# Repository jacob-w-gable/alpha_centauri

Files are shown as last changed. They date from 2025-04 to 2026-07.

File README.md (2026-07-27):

# Alpha Centauri KBD

This is a custom keyboard with a custom keymap that is specifically tailored to my hands and workflow style. It takes heavy inspiration from [crkbd v3](https://github.com/foostan/crkbd). The primary difference is the vertical spacing of the keys, and I have also removed one key from the outside column. The PCB is designed to support either MX or Choc v2 switches without sacrificing LED support. The keymap has been designed for comfort and efficiency, prioritizing typing/programming over other activities such as gaming.

### Assembled Choc Keyboard

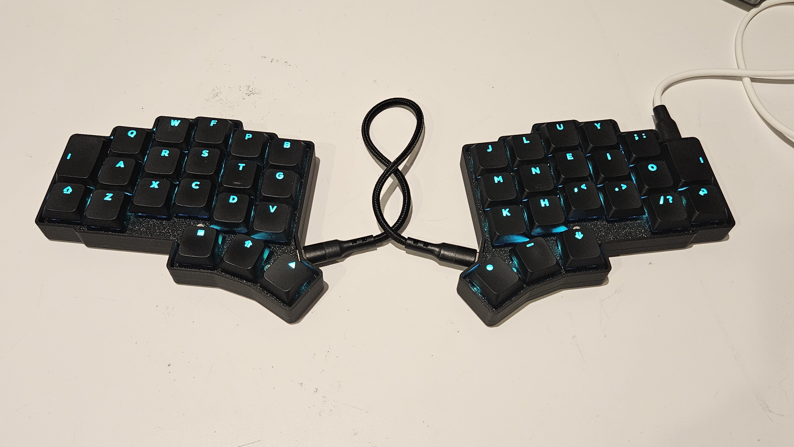
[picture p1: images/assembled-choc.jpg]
Choc variant


### Assembled MX Keyboard

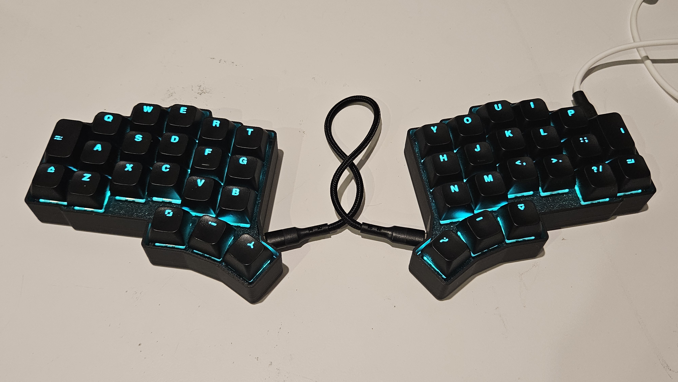
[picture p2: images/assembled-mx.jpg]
MX variant


## Detailed Documentation

- [Quickstart](https://github.com/jacob-w-gable/alpha_centauri/wiki/Quickstart)
- [Designing/Fabricating the PCB](https://github.com/jacob-w-gable/alpha_centauri/wiki/Designing-and-Fabricating-PCB)
- TODO: PCB Assembly
- [Building/Flashing the Firmware](https://github.com/jacob-w-gable/alpha_centauri/wiki/Building-and-Flashing-Firmware)
- TODO: Printing the Case
- TODO: Final Assembly
- [Technical Layer Reference](https://github.com/jacob-w-gable/alpha_centauri/wiki/Technical-Layer-Reference)
- [Design Philosophy](https://github.com/jacob-w-gable/alpha_centauri/wiki/Design)

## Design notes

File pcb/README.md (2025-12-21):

# PCB Files

These are the files required to edit the PCB in Kicad. One thing that makes this PCB stand out, is the fact that you can use hotswap sockets for either MX or Choc style switches, without compromising the ability to use per-key LEDs. While this does unfortunately cut off one of the pads, it does not make an electrical difference.

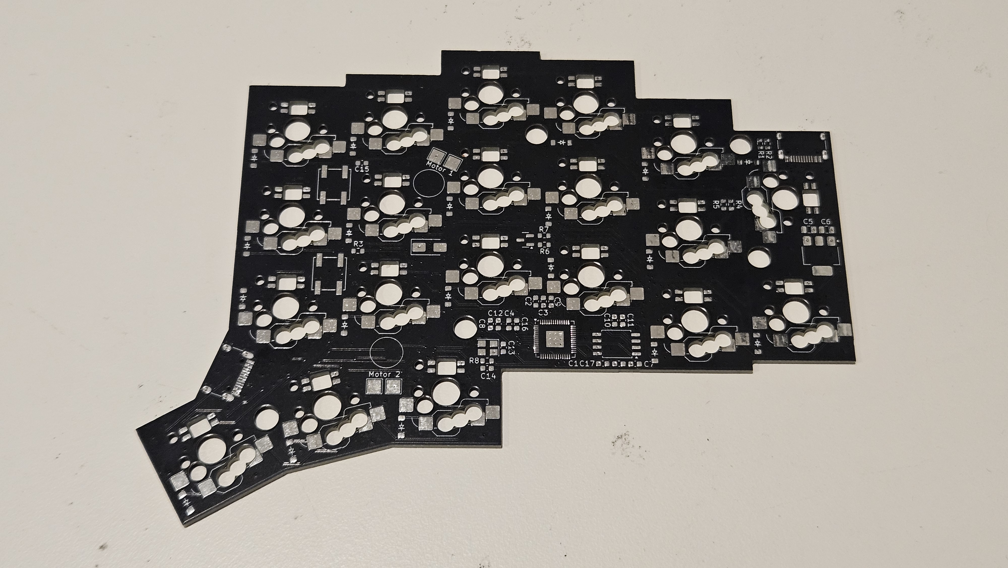
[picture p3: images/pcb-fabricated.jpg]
Fabricated

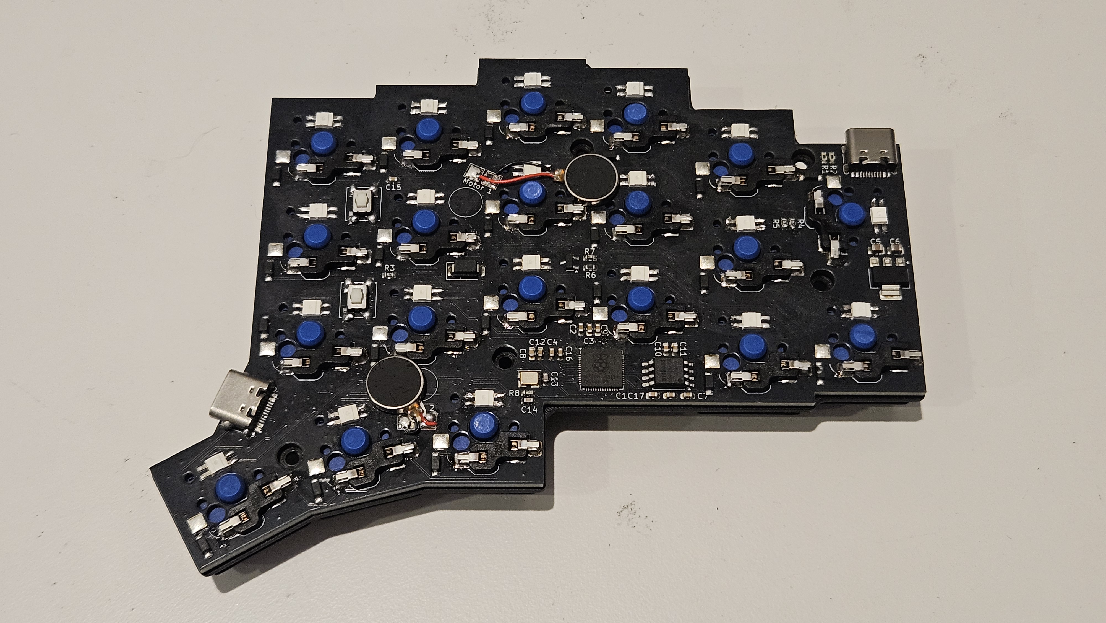
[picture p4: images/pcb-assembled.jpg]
Assembled


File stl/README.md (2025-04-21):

# STL files

These are the files for 3D-printing the keyboard case. These cases are compatible with Amoeba v1 or Amoeba King PCB's. Amoeba Royale's are not supported. The primary difference between the two versions is the structural supports in the middle of the keyboard, which Amoeba Royale's do not provide enough room for. The other difference is that the case for Amoeba King's is slightly larger, to compensate for the slightly larger PCB's. 

Of course, the advantage of Amoeba King's over Amoeba v1's, is support for per-key LED backlighting. 

If you simply want to handwire, either case will do, though the King case will use _slightly_ more material. 

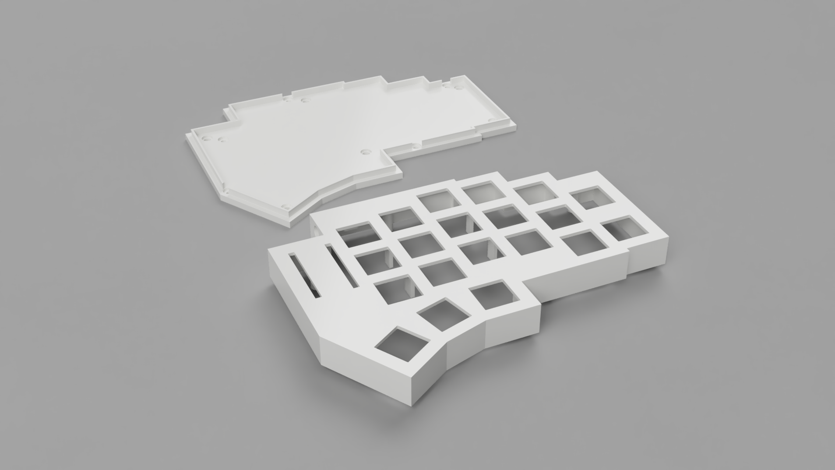
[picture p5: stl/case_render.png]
Case Render


## Printing

No special instructions, considering no supports are necessary. But for consistency, here are some parameters I used:

* Material: PLA
* Layer Height: 0.12mm
* Infill: 15%
* Nozzle Size: 0.4mm

## Firmware Differences

You may find a slight difference in the diode direction, depending on which PCB you are using. For me personally, my King's required

```
  "diode_direction": "ROW2COL",
```

while my v1's required

```
  "diode_direction": "COL2ROW",
```

The direction is ROW2COL by default, so take note of this difference if you want to use Amoeba v1's.

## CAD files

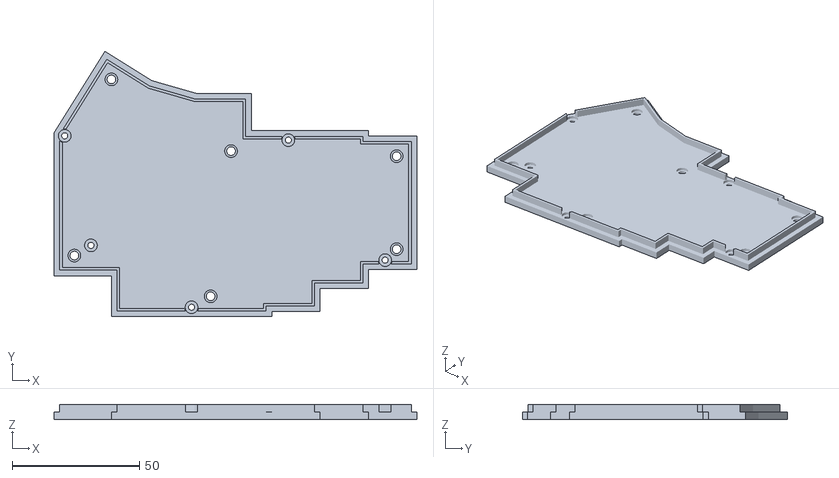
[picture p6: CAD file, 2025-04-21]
stl/amoeba_king/bottom-left.stl
142.5 x 104.2 x 6.00

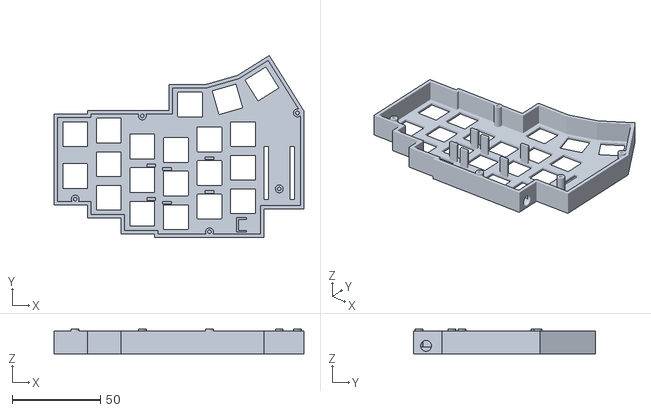
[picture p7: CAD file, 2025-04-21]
stl/amoeba_v1/top-left.stl
141.5 x 103.0 x 14.0

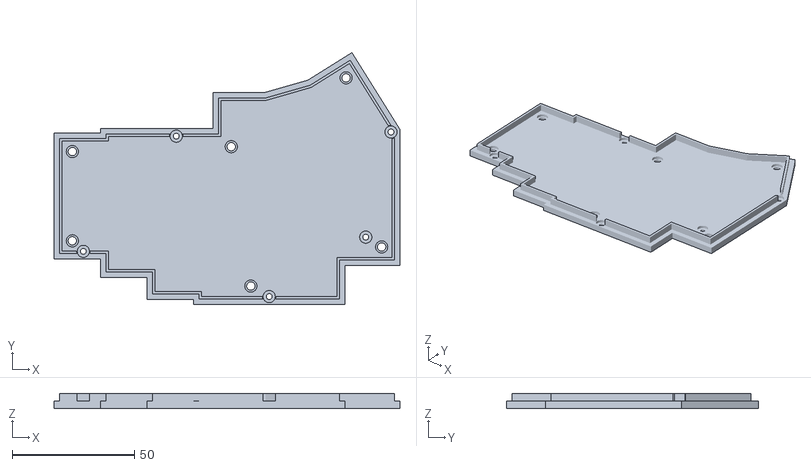
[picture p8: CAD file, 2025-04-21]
stl/amoeba_v1/bottom-right.stl
141.5 x 103.0 x 6.00

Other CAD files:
stl/amoeba_king/bottom-right.stl
stl/amoeba_v1/top-right.stl
stl/amoeba_king/top-left.stl
stl/amoeba_king/top-right.stl
stl/amoeba_v1/bottom-left.stl

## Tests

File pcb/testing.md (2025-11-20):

# Testing PCB

## Before powering on

1. Test GND and 3v3 = 0 ohm
1. Test GND and 5v = 0 ohm
1. Test 3v3 and 5v = 0 ohm
1. Test for continuity between GND and all GND pins on rp2040
1. Test for continuity between 3v3 and all 3v3 pins on rp2040
1. Test for shorts on both sides of all resistors and capacitors. Note: One of the resistors by the mosfet will beep - this is noraml. Also seems like it can happen on the data resistors if you push hard enough.
1. Test for no continuity between each column with each other column
1. Test for no continuity between each row with each other row
1. Test for no continuity between each column with each row
1. Test for continuity between each column with rp2040
1. Test for continuity between each row with rp2040
1. Test for continuity on GND of each capacitor
1. Test for continuity on 3v3 of each 3v3 capacitor
1. Test for continuity on 1v1 of each 1v1 capacitor (just compare them against each other)
1. Test for continuity to 1v1 pins of rp2040 against one the side of one of the 1v1 capacitors
1. Test for no continuity between 3v3 and 1v1 capacitor sides
1. Test for no continuity between the two inputs of the mosfet
1. Test for no continuity between each pin of the flash device
1. Test for continuity between the GND pin of the flash device and GND
1. Test for continuity between the VCC pin of the flash device and 3v3
1. Test for continuity between each pin with the rp2040
1. Test for no continuity between the buttons, unless pressed
1. Test for no continuity between each complimenting side of the data resistors
1. Test for continuity between USB and data resistors
1. Test for continuity between data resistors and rp2040
1. Test for continuity between GND and GND pads of crystal
1. Test for continuity between XIN and rp2040
1. Test for continuity between XOUT (side of a resistor) and rp2040
1. Test for continuity between the other side of that resistor and crystal
1. Test for continuity between the data pins of the slave USB and rp2040
1. Test for continuity between LED input to rp2040
1. Test for continuity between haptic control line to rp2040
1. Test for no continuity between LED input and 3v3
1. Test for no continuity between columns and 3v3
1. Test for no continuity between rows and 3v3
1. Test for no continuity between split kb data line and 3v3
1. Test for no continuity between haptic control line and 3v3
1. Test for no continuity between haptic control line and LED input
1. Test for no continuity between haptic control line and data lines
1. Test for no continuity between LED input and data lines

## After powering on

1. Measure 1v1, 3v3, and 5v voltage.

## Notes

- The top row is the most important. It contains the 1v1 and 3v3 reference points, D+/D-, and QSPI pins. If these pins have good connections while others have poor connections (within reason), then the flashing should at least work.
- Might want to wait to put the LEDs and sockets on until after we can verify that the flashing works

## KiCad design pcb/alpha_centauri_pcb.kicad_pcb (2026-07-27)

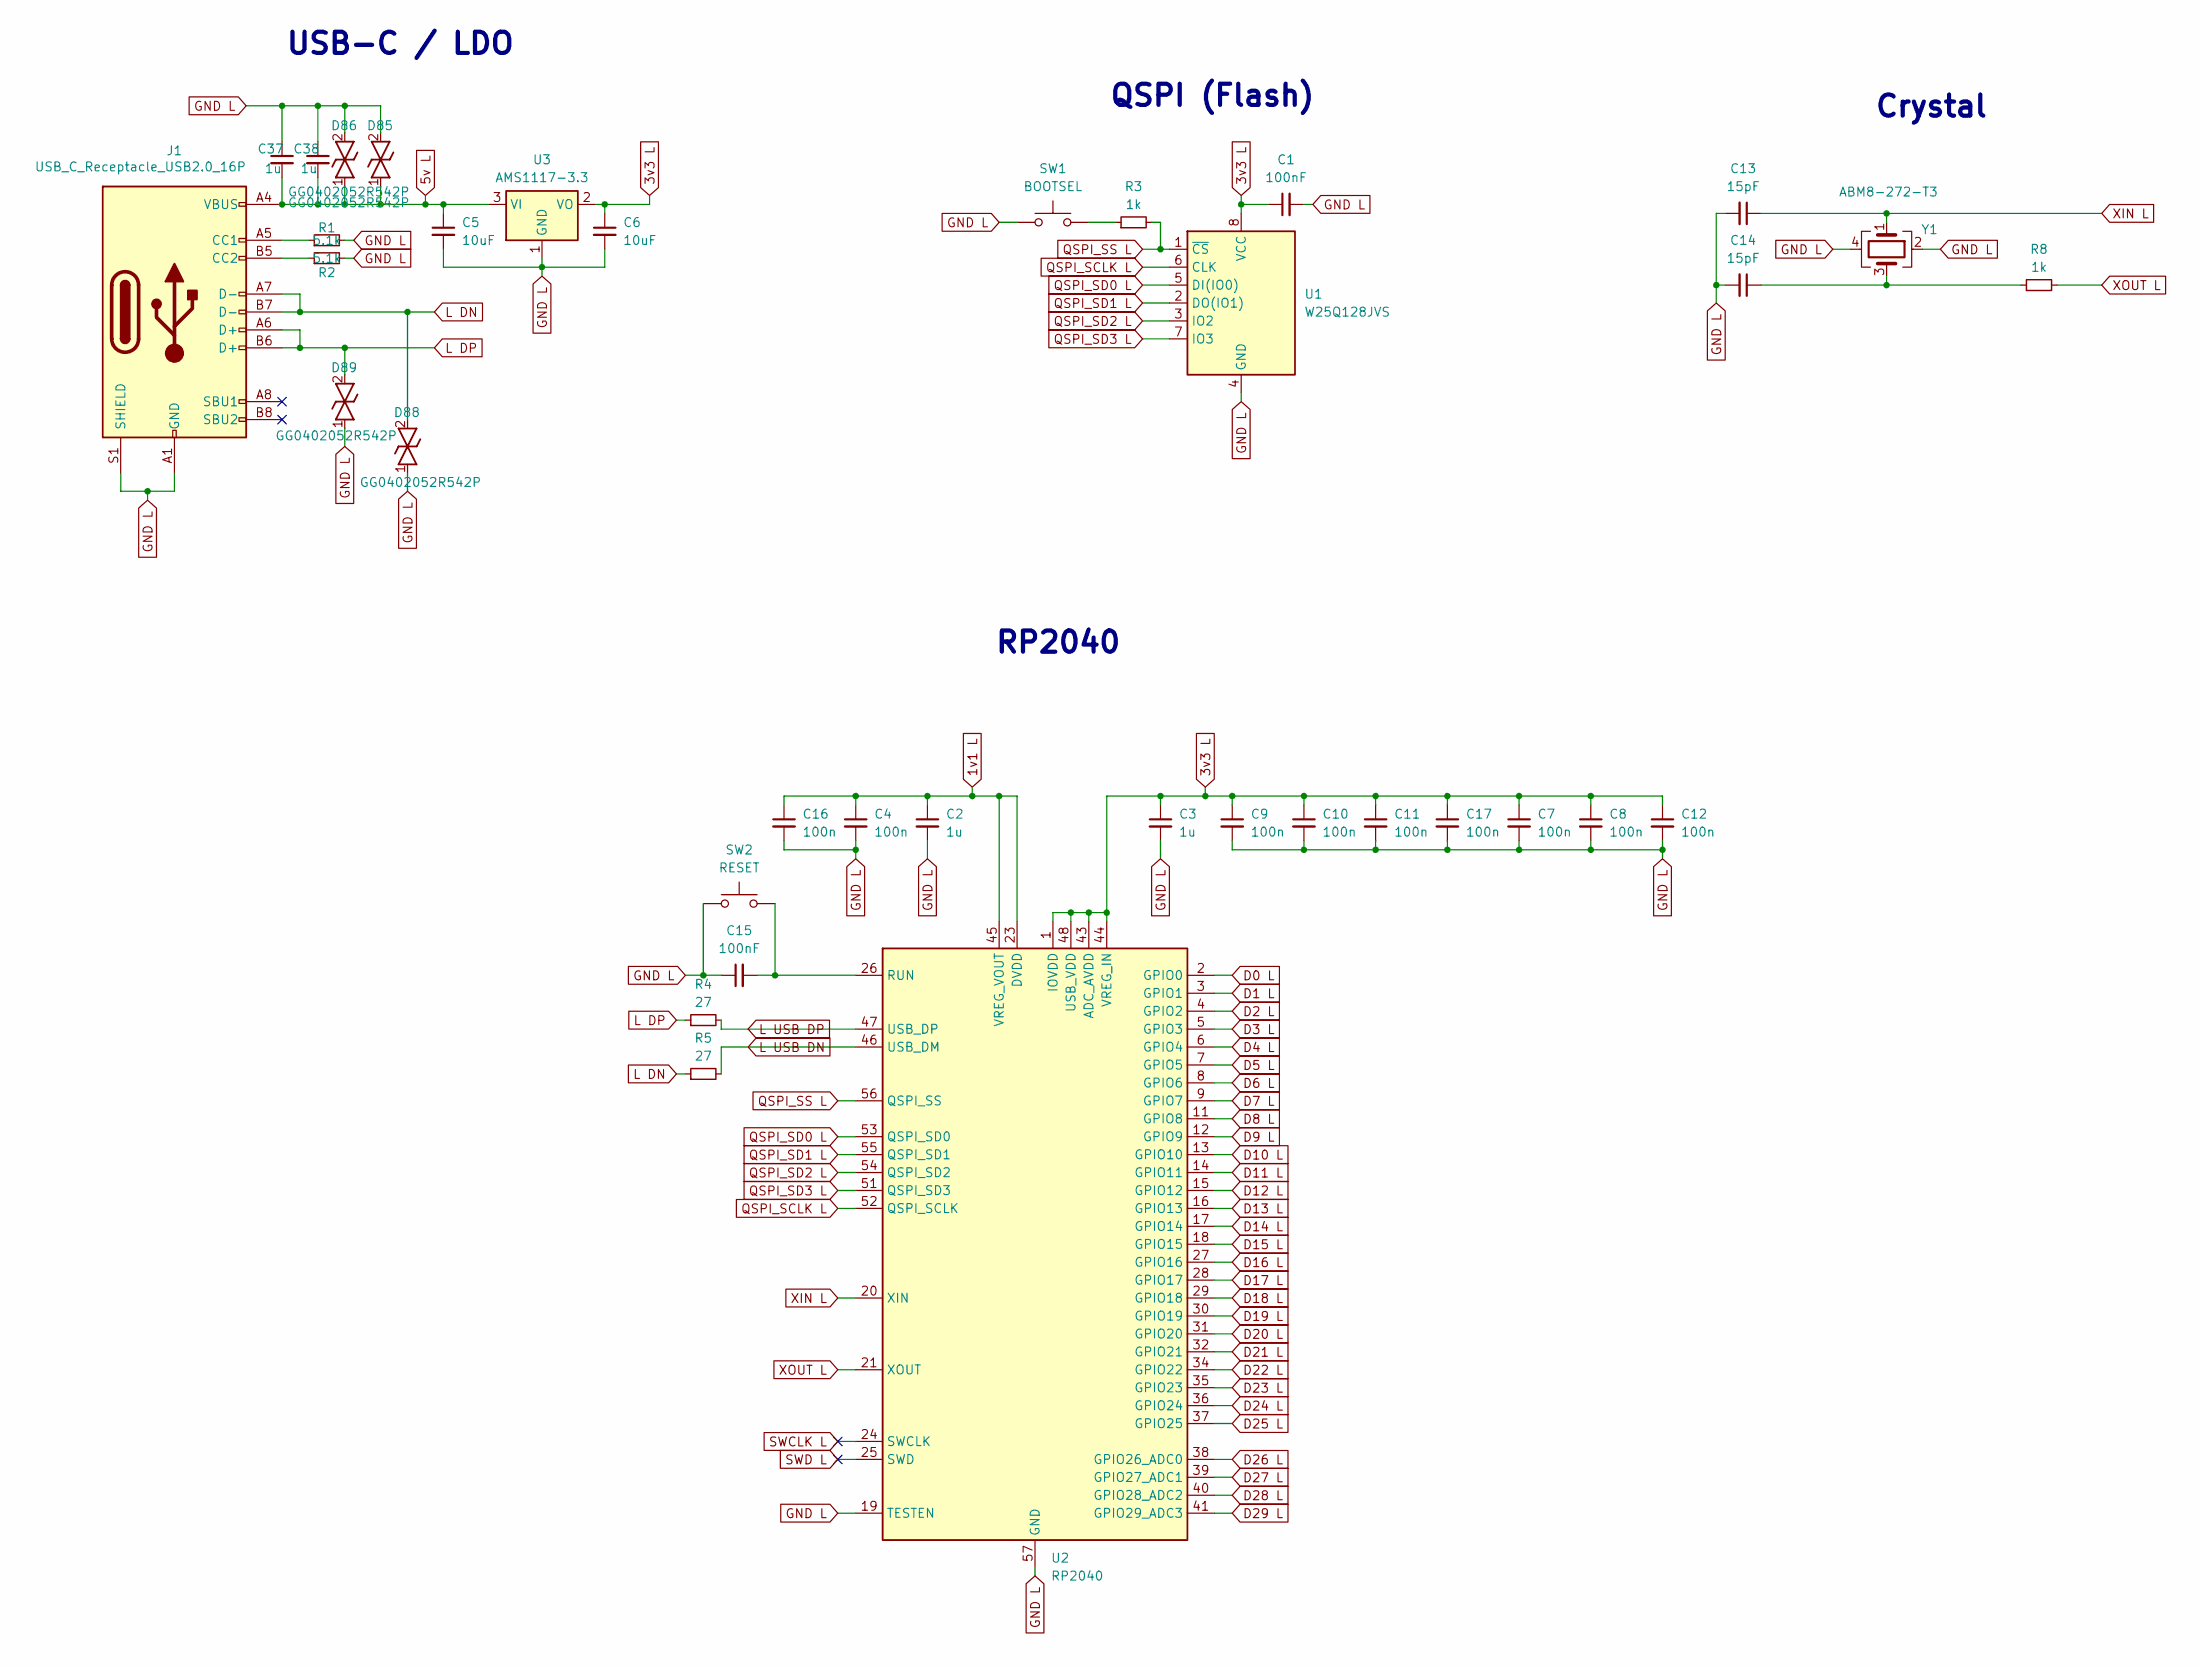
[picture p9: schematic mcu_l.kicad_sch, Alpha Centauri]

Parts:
C1, C15: 100nF; C_0603_1608Metric
C2, C3, C37, C38: 1u; C_0603_1608Metric
C4, C7, C8, C9, C10, C11, C12, C16, C17: 100n; C_0603_1608Metric
C5, C6: 10uF; C_0805_2012Metric
C13, C14: 15pF; C_0603_1608Metric
D85, D86, D88, D89: GG0402052R542P; DIONC1006X55N; Manufacturer_Part_Number GG0402052R542P; Mouser Part Number 581-GG0402052R542P
J1: USB_C_Receptacle_USB2.0_16P; USB_C_Receptacle_HRO_TYPE-C-31-M-12
R1, R2: 5.1k; R_0603_1608Metric
R3, R8: 1k; R_0603_1608Metric
R4, R5: 27; R_0603_1608Metric
SW1: BOOTSEL; EVQP2202M
SW2: RESET; EVQP2202M
U1: W25Q128JVS; SOIC127P790X216-8N
U2: RP2040; QFN-56-1EP_7x7mm_P0.4mm_EP3.2x3.2mm
U3: AMS1117-3.3; SOT-223-3_TabPin2
Y1: ABM8-272-T3; Crystal_SMD_3225-4Pin_3.2x2.5mm

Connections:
1v1 L: C2.1, C4.1, C16.1, U2.23 (DVDD), U2.45 (VREG_VOUT), U2.50 (DVDD)
3v3 L: C1.1, C3.1, C6.1, C7.1, C8.1, C9.1, C10.1, C11.1, C12.1, C17.1, U1.8 (VCC), U2.1 (IOVDD), U2.10 (IOVDD), U2.22 (IOVDD), U2.33 (IOVDD), U2.42 (IOVDD), U2.43 (ADC_AVDD), U2.44 (VREG_IN), U2.48 (USB_VDD), U2.49 (IOVDD), U3.2 (VO)
5v L: C5.1, C37.2, C38.2, D85.1, D86.1, J1.A4 (VBUS), J1.A9 (VBUS), J1.B4 (VBUS), J1.B9 (VBUS), U3.3 (VI); also elsewhere on the board
D0 L: U2.2 (GPIO0); also elsewhere on the board
D1 L: U2.3 (GPIO1)
D2 L: U2.4 (GPIO2)
D3 L: U2.5 (GPIO3)
D4 L: U2.6 (GPIO4); also elsewhere on the board
D5 L: U2.7 (GPIO5); also elsewhere on the board
D6 L: U2.8 (GPIO6); also elsewhere on the board
D7 L: U2.9 (GPIO7); also elsewhere on the board
D8 L: U2.11 (GPIO8); also elsewhere on the board
D9 L: U2.12 (GPIO9); also elsewhere on the board
D10 L: U2.13 (GPIO10)
D11 L: U2.14 (GPIO11)
D12 L: U2.15 (GPIO12)
D13 L: U2.16 (GPIO13)
D14 L: U2.17 (GPIO14)
D15 L: U2.18 (GPIO15)
D16 L: U2.27 (GPIO16)
D17 L: U2.28 (GPIO17)
D18 L: U2.29 (GPIO18)
D19 L: U2.30 (GPIO19)
D20 L: U2.31 (GPIO20); also elsewhere on the board
D21 L: U2.32 (GPIO21)
D22 L: U2.34 (GPIO22); also elsewhere on the board
D23 L: U2.35 (GPIO23)
D24 L: U2.36 (GPIO24)
D25 L: U2.37 (GPIO25)
D26 L: U2.38 (GPIO26_ADC0); also elsewhere on the board
D27 L: U2.39 (GPIO27_ADC1); also elsewhere on the board
D28 L: U2.40 (GPIO28_ADC2); also elsewhere on the board
D29 L: U2.41 (GPIO29_ADC3); also elsewhere on the board
GND L: C1.2, C2.2, C3.2, C4.2, C5.2, C6.2, C7.2, C8.2, C9.2, C10.2, C11.2, C12.2, C13.2, C14.2, C15.1, C16.2, C17.2, C37.1, C38.1, D85.2, D86.2, D88.1, D89.1, J1.A1 (GND), J1.A12 (GND), J1.B1 (GND), J1.B12 (GND), J1.S1 (SHIELD), R1.2, R2.2, SW1.1, SW2.1, U1.4 (GND), U2.19 (TESTEN), U2.57 (GND), U3.1 (GND), Y1.2, Y1.4; also elsewhere on the board
L DN: D88.2, J1.A7 (D-), J1.B7 (D-), R5.1
L DP: D89.2, J1.A6 (D+), J1.B6 (D+), R4.1
L USB DN: R5.2, U2.46 (USB_DM)
L USB DP: R4.2, U2.47 (USB_DP)
unnamed: C14.1, R8.1, Y1.3
unnamed: J1.A5 (CC1), R1.1
unnamed: J1.B5 (CC2), R2.1
unnamed: R3.1, SW1.2
unnamed: C15.2, SW2.2, U2.26 (RUN)
QSPI_SCLK L: U1.6 (CLK), U2.52 (QSPI_SCLK)
QSPI_SD0 L: U1.5 (DI(IO0)), U2.53 (QSPI_SD0)
QSPI_SD1 L: U1.2 (DO(IO1)), U2.55 (QSPI_SD1)
QSPI_SD2 L: U1.3 (IO2), U2.54 (QSPI_SD2)
QSPI_SD3 L: U1.7 (IO3), U2.51 (QSPI_SD3)
QSPI_SS L: R3.2, U1.1 (~CS), U2.56 (QSPI_SS)
SWCLK L: U2.24 (SWCLK)
SWD L: U2.25 (SWD)
XIN L: C13.1, U2.20 (XIN), Y1.1
XOUT L: R8.2, U2.21 (XOUT)

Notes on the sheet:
RP2040
QSPI (Flash)
USB-C / LDO
Crystal

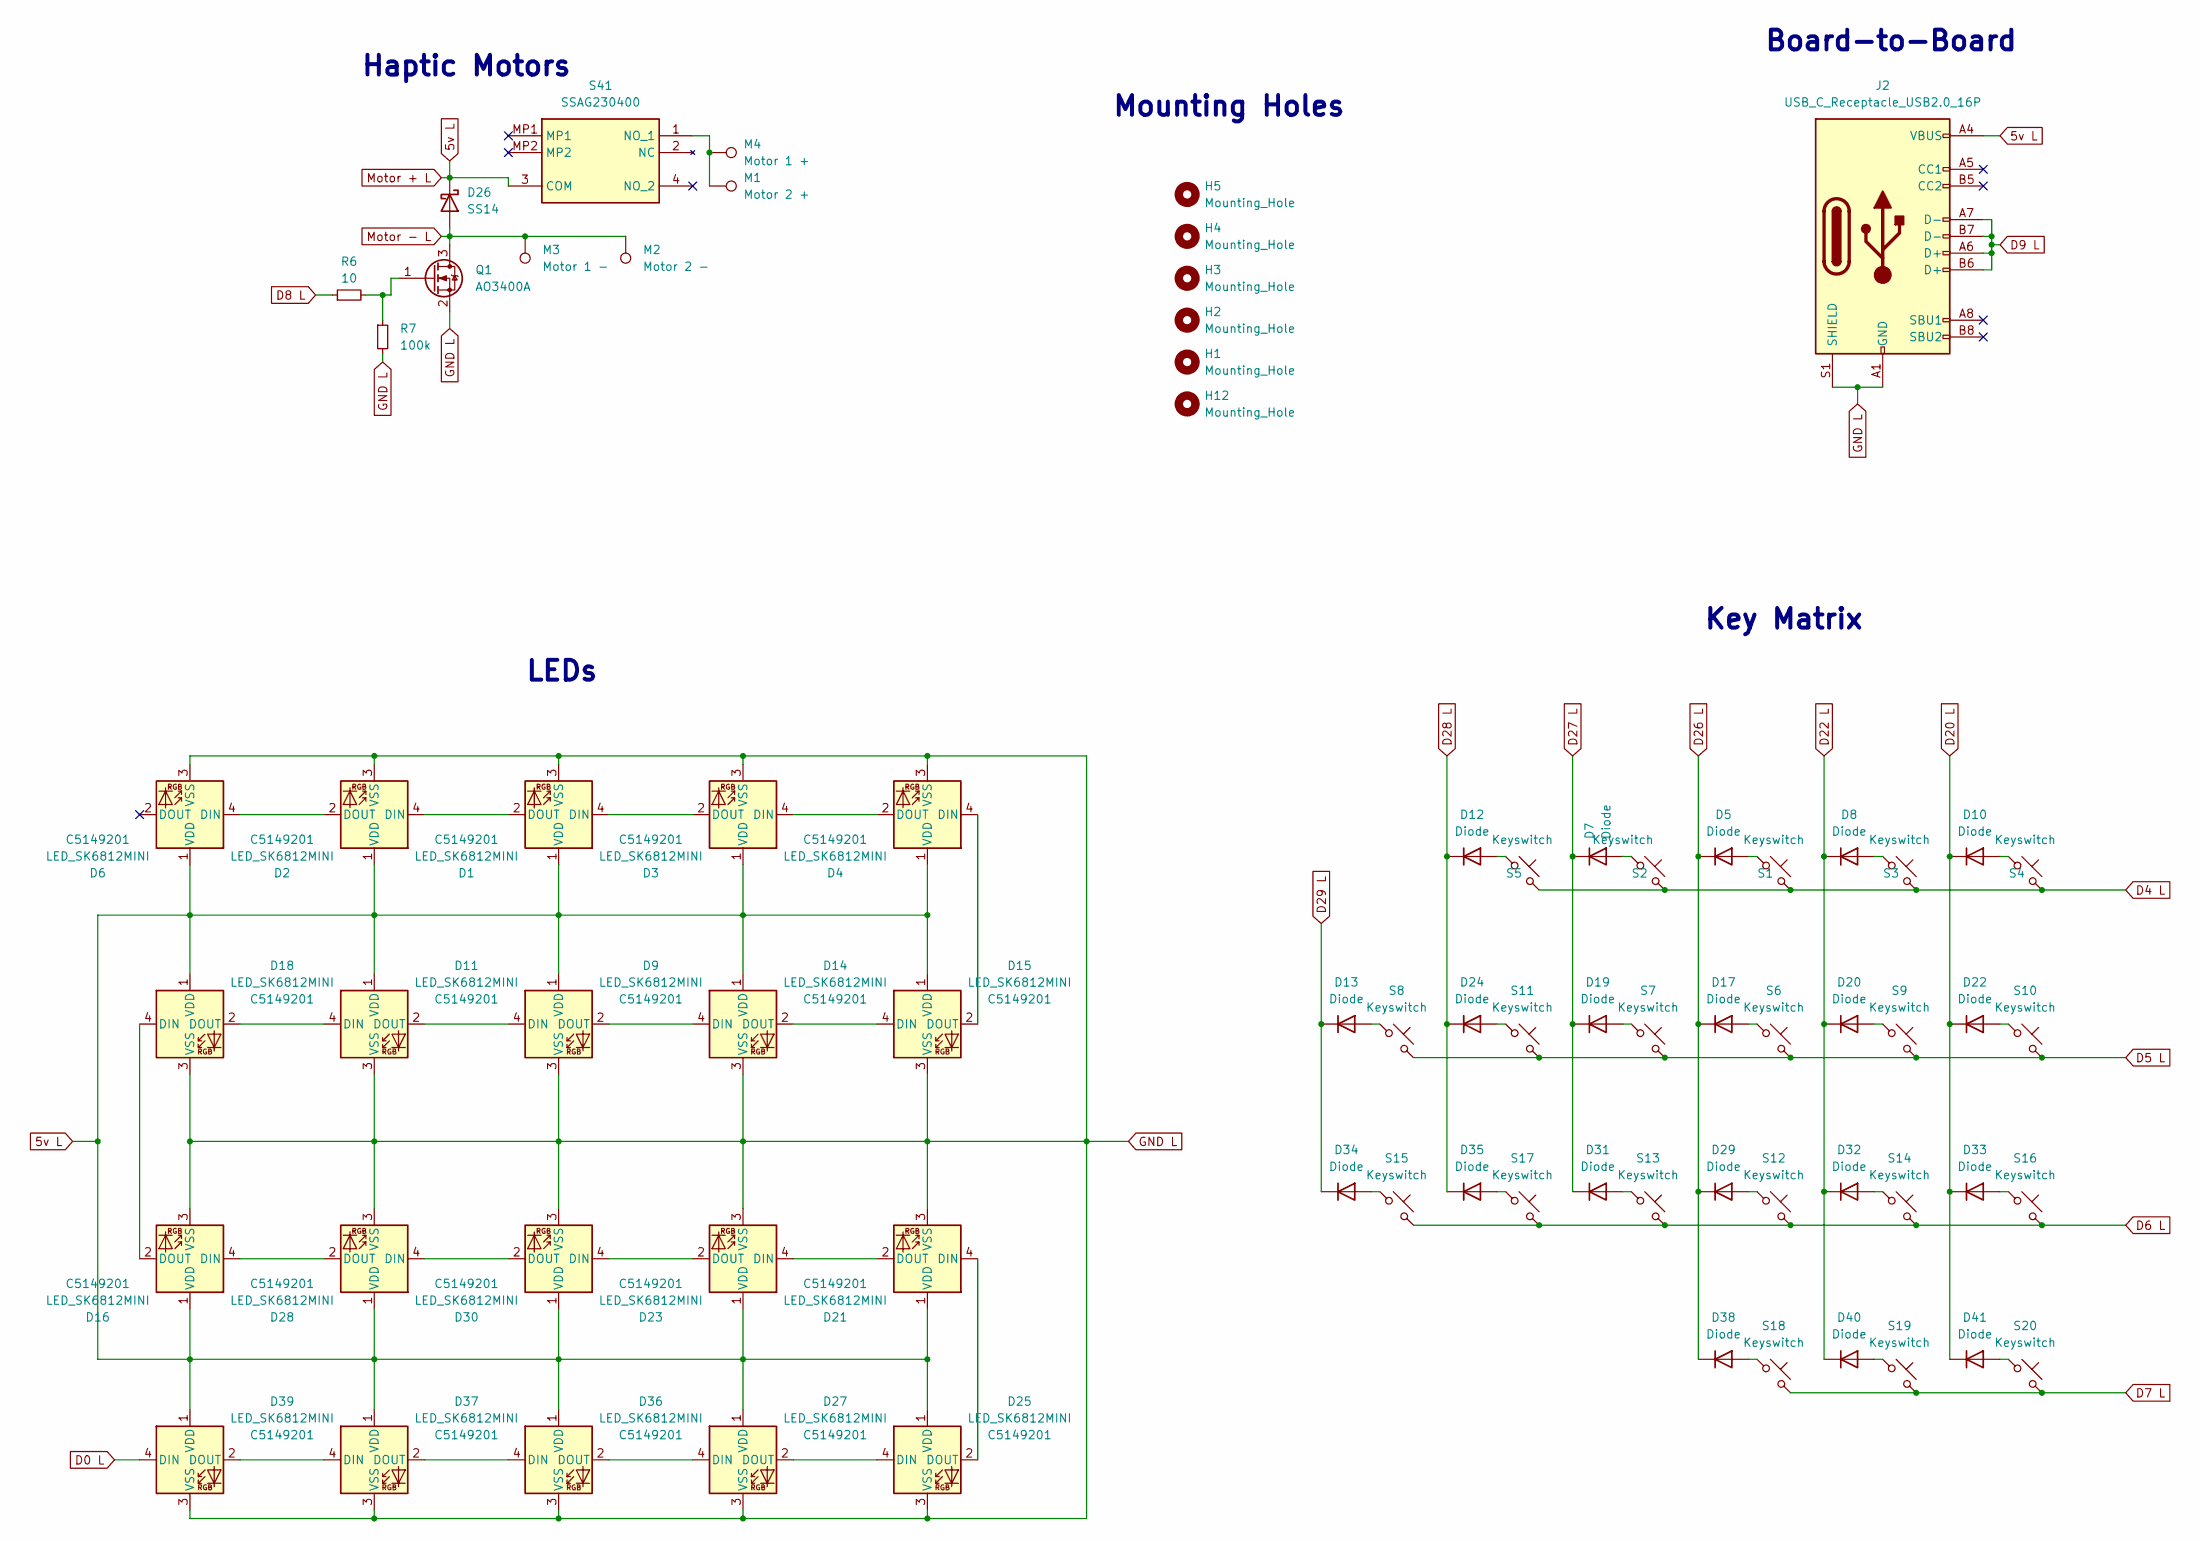
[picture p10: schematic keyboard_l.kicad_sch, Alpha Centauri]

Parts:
D1, D2, D3, D4, D6, D9, D11, D14, D15, D16, D18, D21, D23, D25, D27, D28, D30, D36, D37, D39: LED_SK6812MINI; LCSC C5149201
D5, D7, D8, D10, D12, D13, D17, D19, D20, D22, D24, D29, D31, D32, D33, D34, D35, D38, D40, D41: Diode; Diode_SOD-123
D26: SS14; D_SMA
H1, H2, H3, H4, H5, H12: Mounting_Hole; MountingHole_4.3mm_M4
J2: USB_C_Receptacle_USB2.0_16P; USB_C_Receptacle_HRO_TYPE-C-31-M-12
M1: Motor 2 +; TestPoint_Pad_2.5x2.5mm
M2: Motor 2 -; TestPoint_Pad_2.5x2.5mm
M3: Motor 1 -; TestPoint_Pad_2.5x2.5mm
M4: Motor 1 +; TestPoint_Pad_2.5x2.5mm
Q1: AO3400A; SOT-23
R6: 10; R_0603_1608Metric
R7: 100k; R_0603_1608Metric
S1, S2, S3, S4, S5, S6, S7, S9, S10, S11, S12, S13, S14, S15, S16, S17, S18, S19, S20: Keyswitch; MX_Choc_Hotswap_Hybrid
S8: Keyswitch; MX_Choc_Hotswap_Hybrid_1.5u
S41: SSAG230400; Manufacturer_Part_Number SSAG230400; Mouser Part Number 688-SSAG230400

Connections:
5v L: D1.1 (VDD), D2.1 (VDD), D3.1 (VDD), D4.1 (VDD), D6.1 (VDD), D9.1 (VDD), D11.1 (VDD), D14.1 (VDD), D15.1 (VDD), D16.1 (VDD), D18.1 (VDD), D21.1 (VDD), D23.1 (VDD), D25.1 (VDD), D26.1 (K), D27.1 (VDD), D28.1 (VDD), D30.1 (VDD), D36.1 (VDD), D37.1 (VDD), D39.1 (VDD), J2.A4 (VBUS), J2.A9 (VBUS), J2.B4 (VBUS), J2.B9 (VBUS), S41.3 (COM); also elsewhere on the board
D0 L: D39.4 (DIN); also elsewhere on the board
D4 L: S1.2, S2.2, S3.2, S4.2, S5.2; also elsewhere on the board
D5 L: S6.2, S7.2, S8.2, S9.2, S10.2, S11.2; also elsewhere on the board
D6 L: S12.2, S13.2, S14.2, S15.2, S16.2, S17.2; also elsewhere on the board
D7 L: S18.2, S19.2, S20.2; also elsewhere on the board
D8 L: R6.1; also elsewhere on the board
D9 L: J2.A6 (D+), J2.A7 (D-), J2.B6 (D+), J2.B7 (D-); also elsewhere on the board
D20 L: D10.1 (K), D22.1 (K), D33.1 (K), D41.1 (K); also elsewhere on the board
D22 L: D8.1 (K), D20.1 (K), D32.1 (K), D40.1 (K); also elsewhere on the board
D26 L: D5.1 (K), D17.1 (K), D29.1 (K), D38.1 (K); also elsewhere on the board
D27 L: D7.1 (K), D19.1 (K), D31.1 (K); also elsewhere on the board
D28 L: D12.1 (K), D24.1 (K), D35.1 (K); also elsewhere on the board
D29 L: D13.1 (K), D34.1 (K); also elsewhere on the board
GND L: D1.3 (VSS), D2.3 (VSS), D3.3 (VSS), D4.3 (VSS), D6.3 (VSS), D9.3 (VSS), D11.3 (VSS), D14.3 (VSS), D15.3 (VSS), D16.3 (VSS), D18.3 (VSS), D21.3 (VSS), D23.3 (VSS), D25.3 (VSS), D27.3 (VSS), D28.3 (VSS), D30.3 (VSS), D36.3 (VSS), D37.3 (VSS), D39.3 (VSS), J2.A1 (GND), J2.A12 (GND), J2.B1 (GND), J2.B12 (GND), J2.S1 (SHIELD), Q1.2 (S), R7.2; also elsewhere on the board
Motor - L: D26.2 (A), M2.1 (1_1), M3.1 (1_1), Q1.3 (D)
unnamed: D1.4 (DIN), D3.2 (DOUT)
unnamed: D1.2 (DOUT), D2.4 (DIN)
unnamed: D2.2 (DOUT), D6.4 (DIN)
unnamed: D3.4 (DIN), D4.2 (DOUT)
unnamed: D5.2 (A), S1.1
unnamed: D7.2 (A), S2.1
unnamed: D8.2 (A), S3.1
unnamed: D10.2 (A), S4.1
unnamed: D11.4 (DIN), D18.2 (DOUT)
unnamed: D9.4 (DIN), D11.2 (DOUT)
unnamed: D12.2 (A), S5.1
unnamed: D13.2 (A), S8.1
unnamed: D9.2 (DOUT), D14.4 (DIN)
unnamed: D14.2 (DOUT), D15.4 (DIN)
unnamed: D4.4 (DIN), D15.2 (DOUT)
unnamed: D16.4 (DIN), D28.2 (DOUT)
unnamed: D16.2 (DOUT), D18.4 (DIN)
unnamed: D17.2 (A), S6.1
unnamed: D19.2 (A), S7.1
unnamed: D20.2 (A), S9.1
unnamed: D21.4 (DIN), D25.2 (DOUT)
unnamed: D21.2 (DOUT), D23.4 (DIN)
unnamed: D22.2 (A), S10.1
unnamed: D23.2 (DOUT), D30.4 (DIN)
unnamed: D24.2 (A), S11.1
unnamed: D25.4 (DIN), D27.2 (DOUT)
unnamed: D27.4 (DIN), D36.2 (DOUT)
unnamed: D28.4 (DIN), D30.2 (DOUT)
unnamed: D29.2 (A), S12.1
unnamed: D31.2 (A), S13.1
unnamed: D32.2 (A), S14.1
unnamed: D33.2 (A), S16.1
unnamed: D34.2 (A), S15.1
unnamed: D35.2 (A), S17.1
unnamed: D36.4 (DIN), D37.2 (DOUT)
unnamed: D37.4 (DIN), D39.2 (DOUT)
unnamed: D38.2 (A), S18.1
unnamed: D40.2 (A), S19.1
unnamed: D41.2 (A), S20.1
unnamed: Q1.1 (G), R6.2, R7.1
unnamed: M1.1 (1_1), M4.1 (1_1), S41.1 (NO_1)

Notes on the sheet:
Board-to-Board
Haptic Motors
Key Matrix
LEDs
Mounting Holes

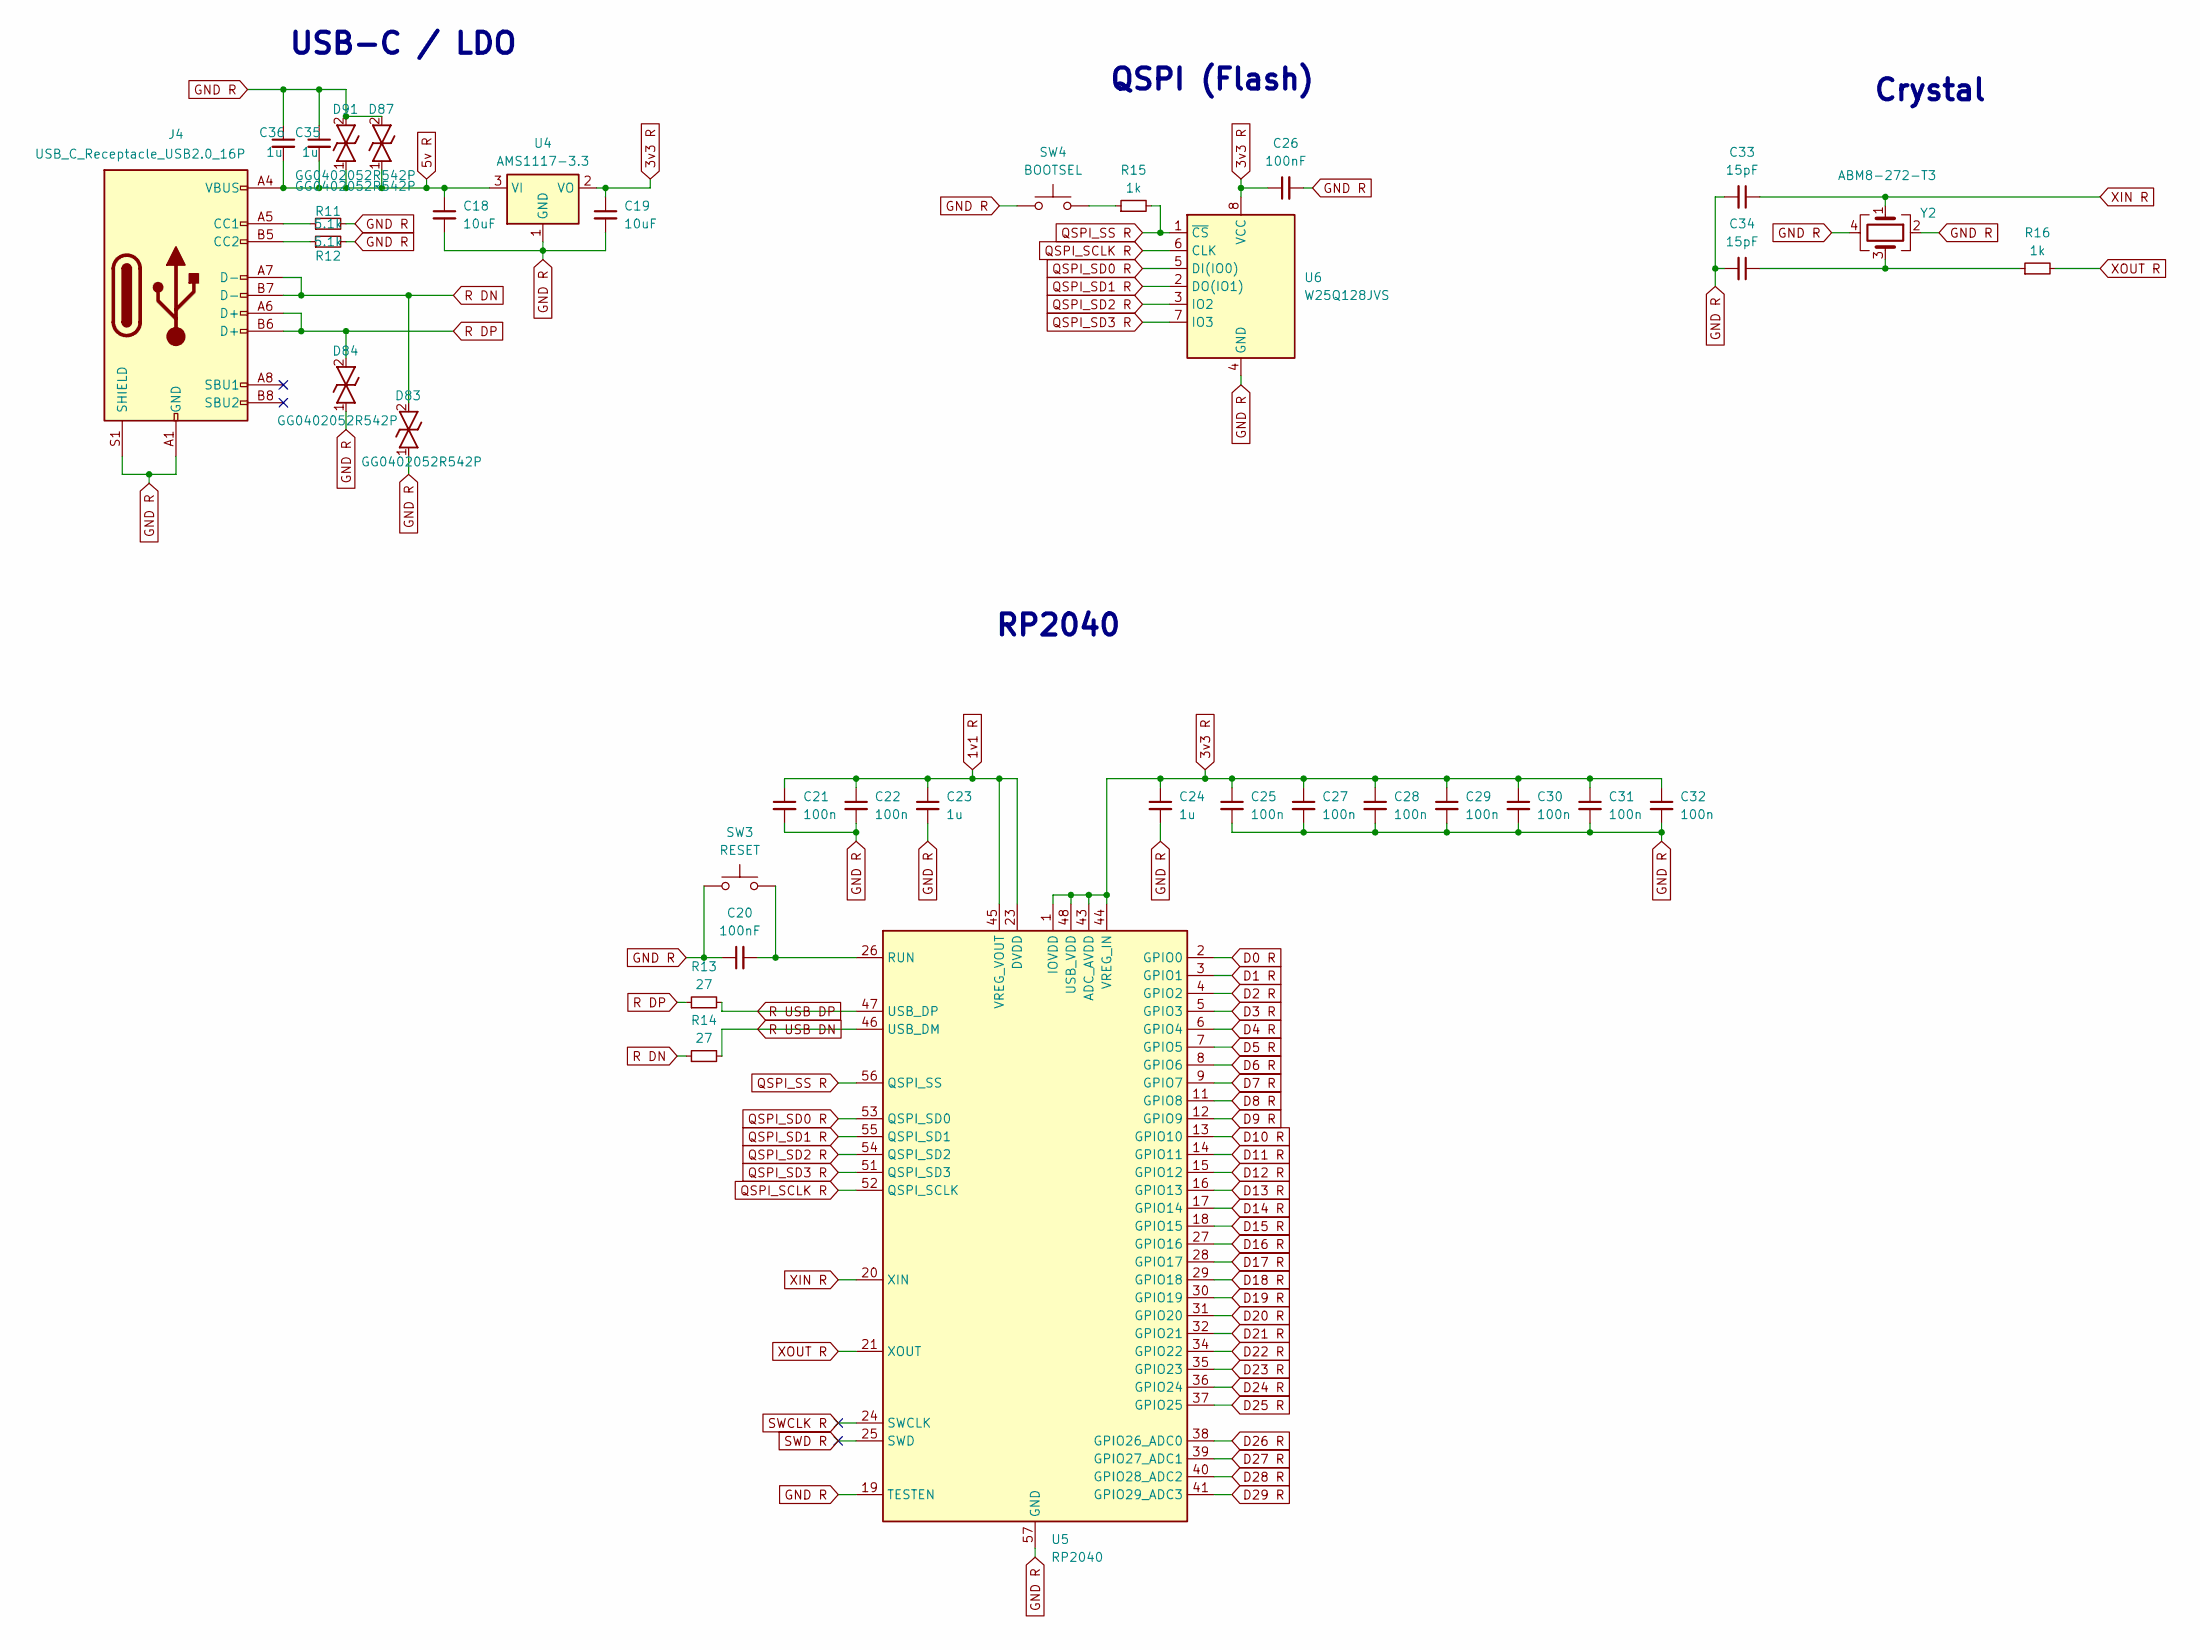
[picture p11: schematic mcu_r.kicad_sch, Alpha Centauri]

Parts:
C18, C19: 10uF; C_0805_2012Metric
C20, C26: 100nF; C_0603_1608Metric
C21, C22, C25, C27, C28, C29, C30, C31, C32: 100n; C_0603_1608Metric
C23, C24, C35, C36: 1u; C_0603_1608Metric
C33, C34: 15pF; C_0603_1608Metric
D83, D84, D87, D91: GG0402052R542P; DIONC1006X55N; Manufacturer_Part_Number GG0402052R542P; Mouser Part Number 581-GG0402052R542P
J4: USB_C_Receptacle_USB2.0_16P; USB_C_Receptacle_HRO_TYPE-C-31-M-12
R11, R12: 5.1k; R_0603_1608Metric
R13, R14: 27; R_0603_1608Metric
R15, R16: 1k; R_0603_1608Metric
SW3: RESET; EVQP2202M
SW4: BOOTSEL; EVQP2202M
U4: AMS1117-3.3; SOT-223-3_TabPin2
U5: RP2040; QFN-56-1EP_7x7mm_P0.4mm_EP3.2x3.2mm
U6: W25Q128JVS; SOIC127P790X216-8N
Y2: ABM8-272-T3; Crystal_SMD_3225-4Pin_3.2x2.5mm

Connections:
1v1 R: C21.1, C22.1, C23.1, U5.23 (DVDD), U5.45 (VREG_VOUT), U5.50 (DVDD)
3v3 R: C19.1, C24.1, C25.1, C26.1, C27.1, C28.1, C29.1, C30.1, C31.1, C32.1, U4.2 (VO), U5.1 (IOVDD), U5.10 (IOVDD), U5.22 (IOVDD), U5.33 (IOVDD), U5.42 (IOVDD), U5.43 (ADC_AVDD), U5.44 (VREG_IN), U5.48 (USB_VDD), U5.49 (IOVDD), U6.8 (VCC)
5v R: C18.1, C35.2, C36.2, D87.1, D91.1, J4.A4 (VBUS), J4.A9 (VBUS), J4.B4 (VBUS), J4.B9 (VBUS), U4.3 (VI); also elsewhere on the board
D0 R: U5.2 (GPIO0); also elsewhere on the board
D1 R: U5.3 (GPIO1)
D2 R: U5.4 (GPIO2)
D3 R: U5.5 (GPIO3)
D4 R: U5.6 (GPIO4); also elsewhere on the board
D5 R: U5.7 (GPIO5); also elsewhere on the board
D6 R: U5.8 (GPIO6); also elsewhere on the board
D7 R: U5.9 (GPIO7); also elsewhere on the board
D8 R: U5.11 (GPIO8); also elsewhere on the board
D9 R: U5.12 (GPIO9); also elsewhere on the board
D10 R: U5.13 (GPIO10)
D11 R: U5.14 (GPIO11)
D12 R: U5.15 (GPIO12)
D13 R: U5.16 (GPIO13)
D14 R: U5.17 (GPIO14)
D15 R: U5.18 (GPIO15)
D16 R: U5.27 (GPIO16)
D17 R: U5.28 (GPIO17)
D18 R: U5.29 (GPIO18)
D19 R: U5.30 (GPIO19)
D20 R: U5.31 (GPIO20); also elsewhere on the board
D21 R: U5.32 (GPIO21)
D22 R: U5.34 (GPIO22); also elsewhere on the board
D23 R: U5.35 (GPIO23)
D24 R: U5.36 (GPIO24)
D25 R: U5.37 (GPIO25)
D26 R: U5.38 (GPIO26_ADC0); also elsewhere on the board
D27 R: U5.39 (GPIO27_ADC1); also elsewhere on the board
D28 R: U5.40 (GPIO28_ADC2); also elsewhere on the board
D29 R: U5.41 (GPIO29_ADC3); also elsewhere on the board
GND R: C18.2, C19.2, C20.1, C21.2, C22.2, C23.2, C24.2, C25.2, C26.2, C27.2, C28.2, C29.2, C30.2, C31.2, C32.2, C33.2, C34.2, C35.1, C36.1, D83.1, D84.1, D87.2, D91.2, J4.A1 (GND), J4.A12 (GND), J4.B1 (GND), J4.B12 (GND), J4.S1 (SHIELD), R11.2, R12.2, SW3.1, SW4.1, U4.1 (GND), U5.19 (TESTEN), U5.57 (GND), U6.4 (GND), Y2.2, Y2.4; also elsewhere on the board
unnamed: C34.1, R16.1, Y2.3
unnamed: J4.A5 (CC1), R11.1
unnamed: J4.B5 (CC2), R12.1
unnamed: R15.1, SW4.2
unnamed: C20.2, SW3.2, U5.26 (RUN)
QSPI_SCLK R: U5.52 (QSPI_SCLK), U6.6 (CLK)
QSPI_SD0 R: U5.53 (QSPI_SD0), U6.5 (DI(IO0))
QSPI_SD1 R: U5.55 (QSPI_SD1), U6.2 (DO(IO1))
QSPI_SD2 R: U5.54 (QSPI_SD2), U6.3 (IO2)
QSPI_SD3 R: U5.51 (QSPI_SD3), U6.7 (IO3)
QSPI_SS R: R15.2, U5.56 (QSPI_SS), U6.1 (~CS)
R DN: D83.2, J4.A7 (D-), J4.B7 (D-), R14.1
R DP: D84.2, J4.A6 (D+), J4.B6 (D+), R13.1
R USB DN: R14.2, U5.46 (USB_DM)
R USB DP: R13.2, U5.47 (USB_DP)
SWCLK R: U5.24 (SWCLK)
SWD R: U5.25 (SWD)
XIN R: C33.1, U5.20 (XIN), Y2.1
XOUT R: R16.2, U5.21 (XOUT)

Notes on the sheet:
RP2040
QSPI (Flash)
Crystal
USB-C / LDO

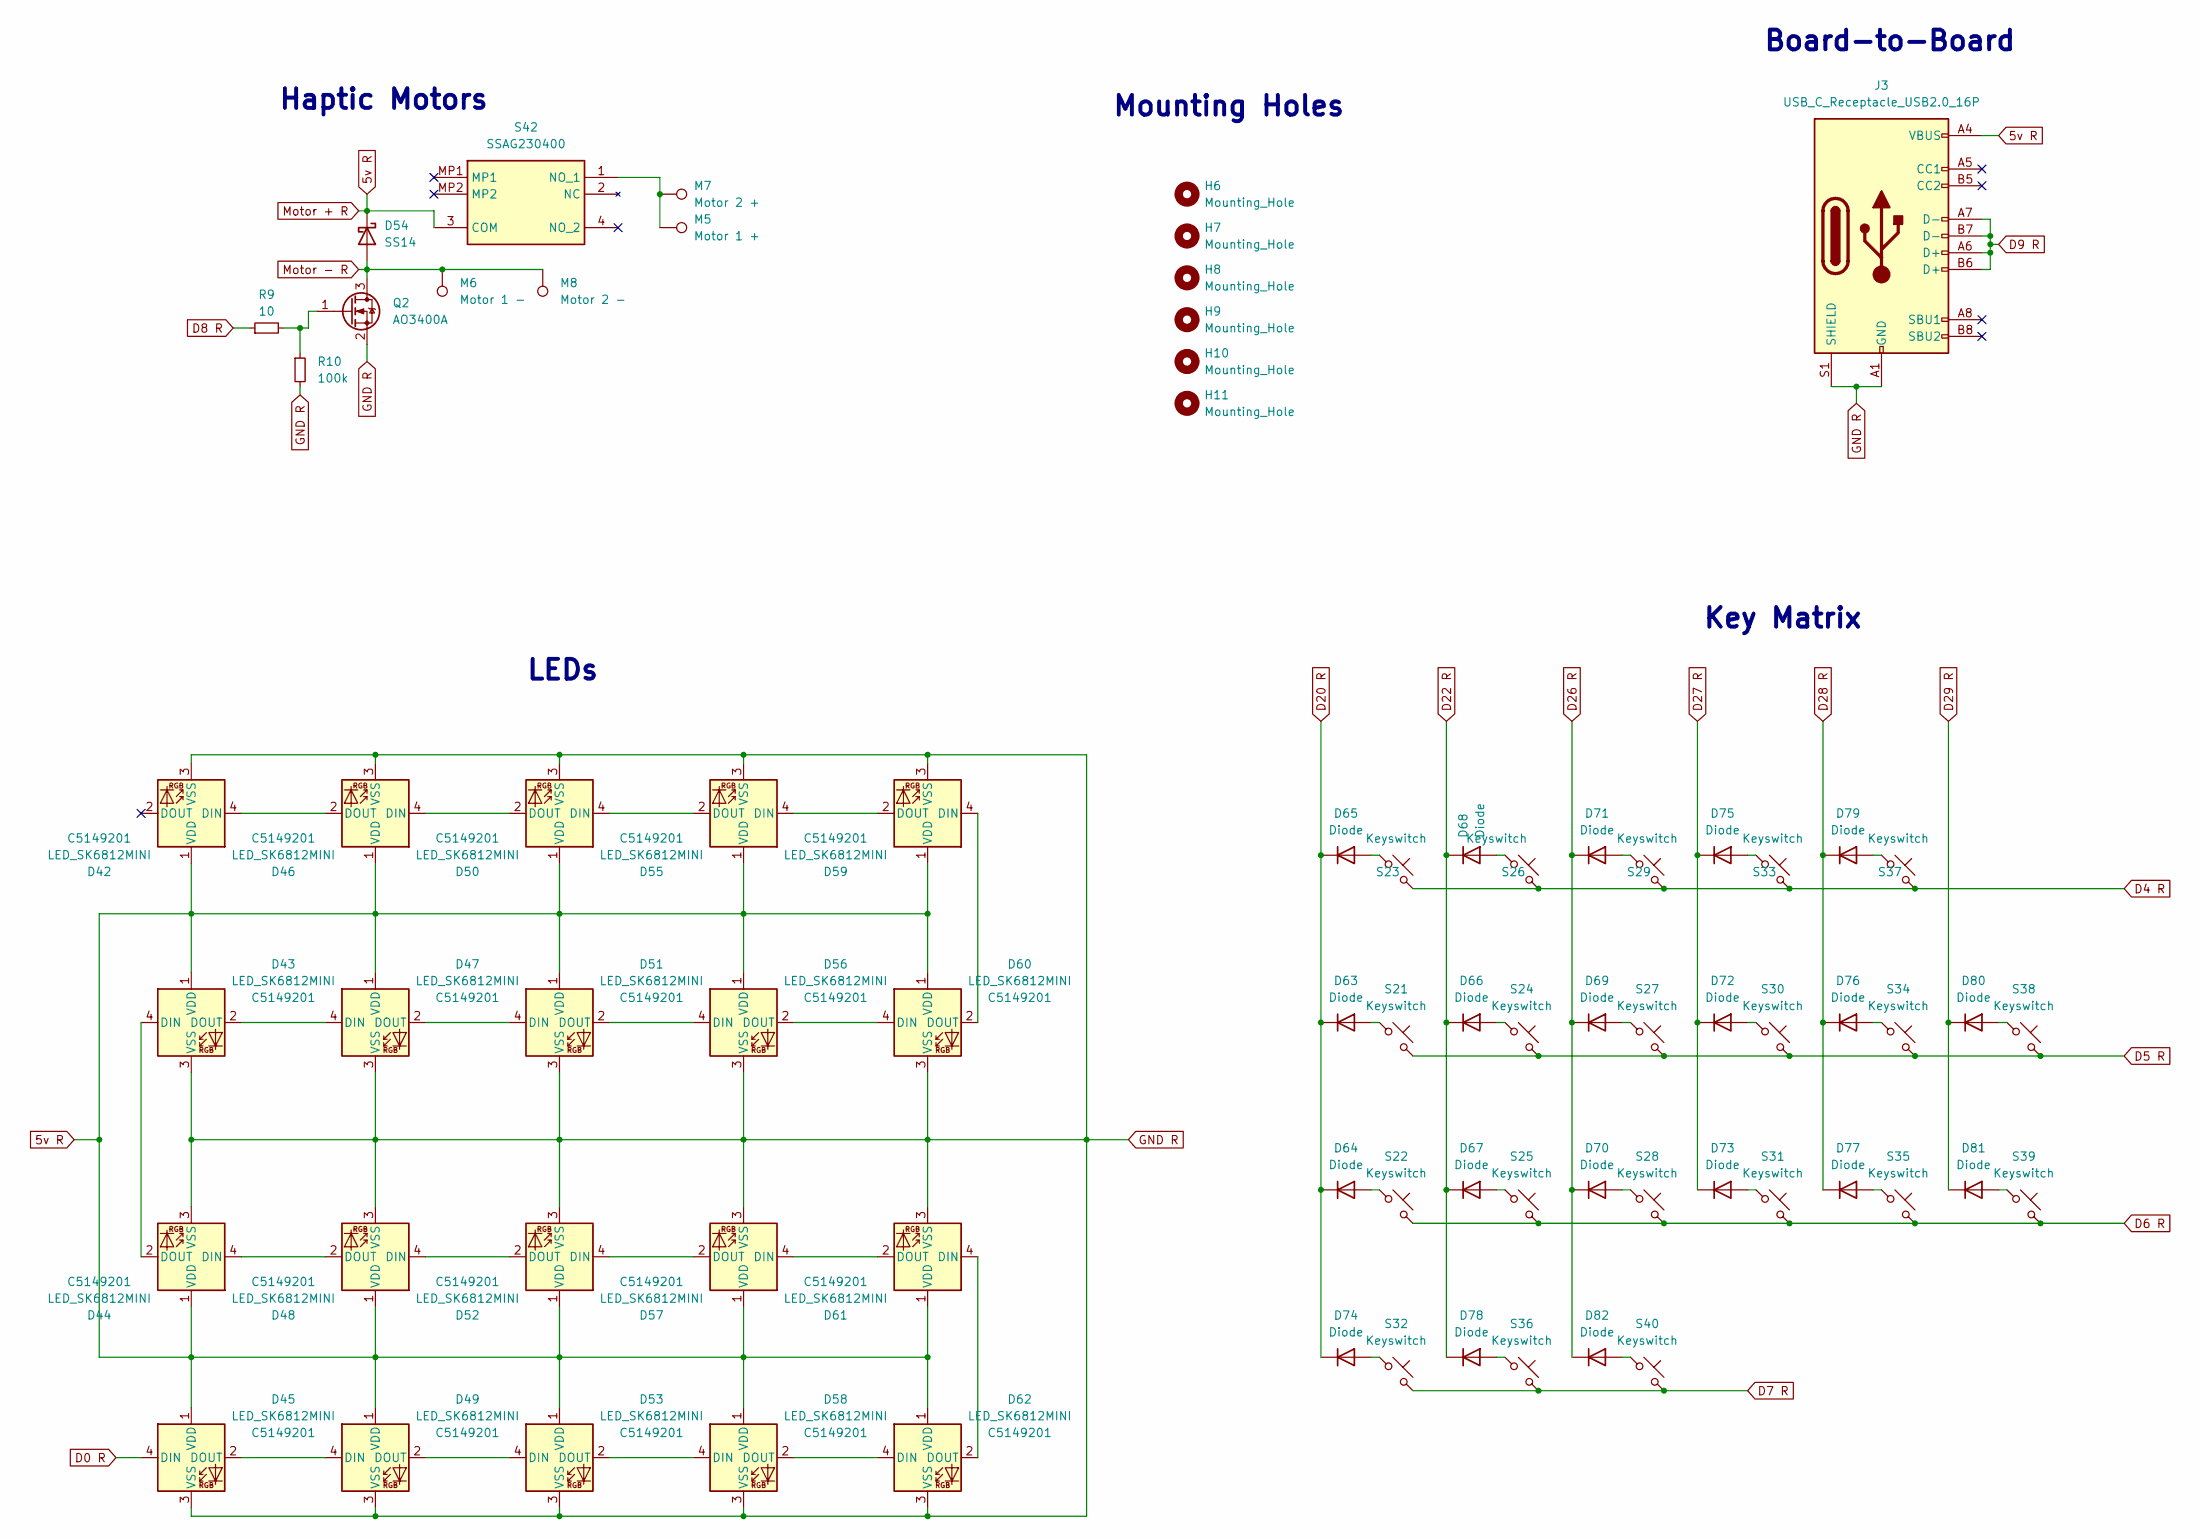
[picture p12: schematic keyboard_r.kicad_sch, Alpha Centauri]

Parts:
D42, D43, D44, D45, D46, D47, D48, D49, D50, D51, D52, D53, D55, D56, D57, D58, D59, D60, D61, D62: LED_SK6812MINI; LCSC C5149201
D54: SS14; D_SMA
D63, D64, D65, D66, D67, D68, D69, D70, D71, D72, D73, D74, D75, D76, D77, D78, D79, D80, D81, D82: Diode; Diode_SOD-123
H6, H7, H8, H9, H10, H11: Mounting_Hole; MountingHole_4.3mm_M4
J3: USB_C_Receptacle_USB2.0_16P; USB_C_Receptacle_HRO_TYPE-C-31-M-12
M5: Motor 1 +; TestPoint_Pad_2.5x2.5mm
M6: Motor 1 -; TestPoint_Pad_2.5x2.5mm
M7: Motor 2 +; TestPoint_Pad_2.5x2.5mm
M8: Motor 2 -; TestPoint_Pad_2.5x2.5mm
Q2: AO3400A; SOT-23
R9: 10; R_0603_1608Metric
R10: 100k; R_0603_1608Metric
S21, S22, S23, S24, S25, S26, S27, S28, S29, S30, S31, S32, S33, S34, S35, S36, S37, S39, S40: Keyswitch; MX_Choc_Hotswap_Hybrid
S38: Keyswitch; MX_Choc_Hotswap_Hybrid_1.5u
S42: SSAG230400; Manufacturer_Part_Number SSAG230400; Mouser Part Number 688-SSAG230400

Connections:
5v R: D42.1 (VDD), D43.1 (VDD), D44.1 (VDD), D45.1 (VDD), D46.1 (VDD), D47.1 (VDD), D48.1 (VDD), D49.1 (VDD), D50.1 (VDD), D51.1 (VDD), D52.1 (VDD), D53.1 (VDD), D54.1 (K), D55.1 (VDD), D56.1 (VDD), D57.1 (VDD), D58.1 (VDD), D59.1 (VDD), D60.1 (VDD), D61.1 (VDD), D62.1 (VDD), J3.A4 (VBUS), J3.A9 (VBUS), J3.B4 (VBUS), J3.B9 (VBUS), S42.3 (COM); also elsewhere on the board
D0 R: D45.4 (DIN); also elsewhere on the board
D4 R: S23.2, S26.2, S29.2, S33.2, S37.2; also elsewhere on the board
D5 R: S21.2, S24.2, S27.2, S30.2, S34.2, S38.2; also elsewhere on the board
D6 R: S22.2, S25.2, S28.2, S31.2, S35.2, S39.2; also elsewhere on the board
D7 R: S32.2, S36.2, S40.2; also elsewhere on the board
D8 R: R9.1; also elsewhere on the board
D9 R: J3.A6 (D+), J3.A7 (D-), J3.B6 (D+), J3.B7 (D-); also elsewhere on the board
D20 R: D63.1 (K), D64.1 (K), D65.1 (K), D74.1 (K); also elsewhere on the board
D22 R: D66.1 (K), D67.1 (K), D68.1 (K), D78.1 (K); also elsewhere on the board
D26 R: D69.1 (K), D70.1 (K), D71.1 (K), D82.1 (K); also elsewhere on the board
D27 R: D72.1 (K), D73.1 (K), D75.1 (K); also elsewhere on the board
D28 R: D76.1 (K), D77.1 (K), D79.1 (K); also elsewhere on the board
D29 R: D80.1 (K), D81.1 (K); also elsewhere on the board
GND R: D42.3 (VSS), D43.3 (VSS), D44.3 (VSS), D45.3 (VSS), D46.3 (VSS), D47.3 (VSS), D48.3 (VSS), D49.3 (VSS), D50.3 (VSS), D51.3 (VSS), D52.3 (VSS), D53.3 (VSS), D55.3 (VSS), D56.3 (VSS), D57.3 (VSS), D58.3 (VSS), D59.3 (VSS), D60.3 (VSS), D61.3 (VSS), D62.3 (VSS), J3.A1 (GND), J3.A12 (GND), J3.B1 (GND), J3.B12 (GND), J3.S1 (SHIELD), Q2.2 (S), R10.2; also elsewhere on the board
Motor - R: D54.2 (A), M6.1 (1_1), M8.1 (1_1), Q2.3 (D)
unnamed: D42.4 (DIN), D46.2 (DOUT)
unnamed: D43.4 (DIN), D44.2 (DOUT)
unnamed: D43.2 (DOUT), D47.4 (DIN)
unnamed: D44.4 (DIN), D48.2 (DOUT)
unnamed: D45.2 (DOUT), D49.4 (DIN)
unnamed: D46.4 (DIN), D50.2 (DOUT)
unnamed: D47.2 (DOUT), D51.4 (DIN)
unnamed: D48.4 (DIN), D52.2 (DOUT)
unnamed: D49.2 (DOUT), D53.4 (DIN)
unnamed: D50.4 (DIN), D55.2 (DOUT)
unnamed: D51.2 (DOUT), D56.4 (DIN)
unnamed: D52.4 (DIN), D57.2 (DOUT)
unnamed: D53.2 (DOUT), D58.4 (DIN)
unnamed: D55.4 (DIN), D59.2 (DOUT)
unnamed: D56.2 (DOUT), D60.4 (DIN)
unnamed: D57.4 (DIN), D61.2 (DOUT)
unnamed: D58.2 (DOUT), D62.4 (DIN)
unnamed: D59.4 (DIN), D60.2 (DOUT)
unnamed: D61.4 (DIN), D62.2 (DOUT)
unnamed: D63.2 (A), S21.1
unnamed: D64.2 (A), S22.1
unnamed: D65.2 (A), S23.1
unnamed: D66.2 (A), S24.1
unnamed: D67.2 (A), S25.1
unnamed: D68.2 (A), S26.1
unnamed: D69.2 (A), S27.1
unnamed: D70.2 (A), S28.1
unnamed: D71.2 (A), S29.1
unnamed: D72.2 (A), S30.1
unnamed: D73.2 (A), S31.1
unnamed: D74.2 (A), S32.1
unnamed: D75.2 (A), S33.1
unnamed: D76.2 (A), S34.1
unnamed: D77.2 (A), S35.1
unnamed: D78.2 (A), S36.1
unnamed: D79.2 (A), S37.1
unnamed: D80.2 (A), S38.1
unnamed: D81.2 (A), S39.1
unnamed: D82.2 (A), S40.1
unnamed: Q2.1 (G), R9.2, R10.1
unnamed: M5.1 (1_1), M7.1 (1_1), S42.1 (NO_1)

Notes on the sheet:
LEDs
Haptic Motors
Board-to-Board
Mounting Holes
Key Matrix

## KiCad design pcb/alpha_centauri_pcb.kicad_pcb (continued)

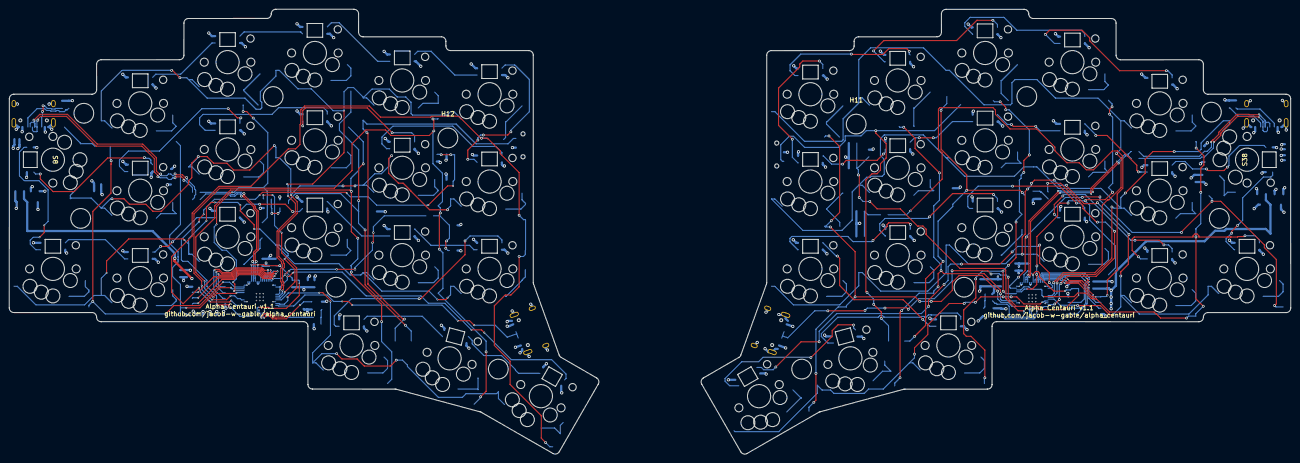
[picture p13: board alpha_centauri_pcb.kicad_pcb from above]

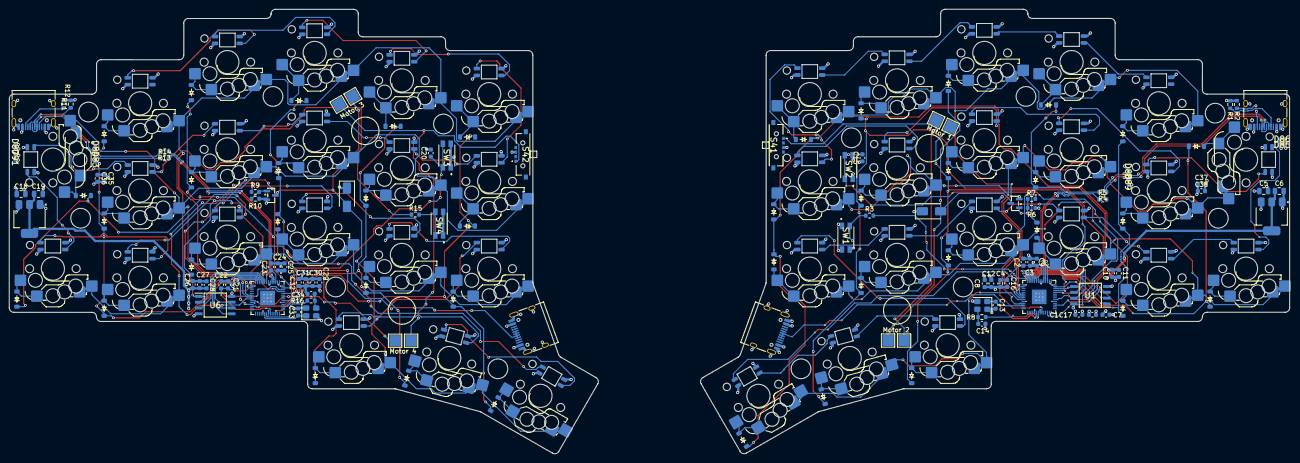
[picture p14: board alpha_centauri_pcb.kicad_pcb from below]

Board: 4 copper layers, 279.5 x 97.0 mm, 224 parts (172 on the bottom side), 152 nets.

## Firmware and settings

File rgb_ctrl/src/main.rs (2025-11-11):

use crate::{args::parse_args, device::Device};
use std::path::Path;
use tracing_subscriber::{fmt, layer::SubscriberExt, util::SubscriberInitExt, EnvFilter, Layer};

mod args;
mod command;
mod device;
mod usb;

fn main() -> anyhow::Result<()> {
    initialize_tracing();

    let command = parse_args()?;

    let home_dir = std::env::var("HOME")?;
    let keyboard_config_path = Path::new(&home_dir)
        .join("Projects")
        .join("alpha_centauri")
        .join("keyboard.json");

    tracing::debug!("Using keyboard config path: {:?}", keyboard_config_path);

    let usb = usb::get_usb(keyboard_config_path)?;
    let device = Device::new(usb)?;

    device.command(command)
}

fn initialize_tracing() {
    let env_filter_layer =
        EnvFilter::try_from_default_env().unwrap_or_else(|_| EnvFilter::new("info,rgb_ctrl=debug"));
    let fmt_layer = fmt::layer()
        .with_target(false)
        .with_filter(env_filter_layer);

    tracing_subscriber::registry().with(fmt_layer).init();
}

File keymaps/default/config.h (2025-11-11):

#pragma once

#define RP2040_BOOTLOADER_DOUBLE_TAP_RESET
#define RP2040_BOOTLOADER_DOUBLE_TAP_RESET_TIMEOUT 250U

#define RAW_USAGE_PAGE 0xFF60
#define RAW_USAGE_ID 0x61

// Solenoid config
#define SOLENOID_PIN GP8
#define SOLENOID_MAX_DWELL 250
#define SOLENOID_MIN_DWELL 4
#define SOLENOID_DEFAULT_DWELL 30
#define SOLENOID_DWELL_STEP_SIZE 10
#define NO_HAPTIC_ALPHA
#define NO_HAPTIC_PUNCTUATION
#define NO_HAPTIC_NAV
#define NO_HAPTIC_NUMERIC

// Data syncing
#define SPLIT_HAPTIC_ENABLE
#define SPLIT_ACTIVITY_ENABLE
#define SPLIT_LAYER_STATE_ENABLE
#define SPLIT_LED_STATE_ENABLE
#define SPLIT_WPM_ENABLE

// #define SWAP_HANDS_ENABLE

#define UNICODE_SELECTED_MODES UNICODE_MODE_LINUX

/* Hand configuration */
// If `MASTER_LEFT` and `MASTER_RIGHT` are both undefined, define `EE_HANDS`.
#ifndef MASTER_LEFT
#ifndef MASTER_RIGHT
#define EE_HANDS
#endif
#endif

// Split configuration
#define SERIAL_USART_TX_PIN GP9
#define SPLIT_CONNECTION_CHECK_TIMEOUT 100

#define TAPPING_TERM_PER_KEY
#define QUICK_TAP_TERM 120

#define PERMISSIVE_HOLD_PER_KEY
#define HOLD_ON_OTHER_KEY_PRESS_PER_KEY

#define OLED_TIMEOUT 120000
#define OLED_BRIGHTNESS 120

#define BOTH_SHIFTS_TURNS_ON_CAPS_WORD

// mouse keys
#define MK_COMBINED
#define MOUSEKEY_DELAY 2
#define MOUSEKEY_INTERVAL 5
#define MOUSEKEY_MOVE_DELTA 2
#define MOUSEKEY_MAX_SPEED 7
#define MK_C_OFFSET_1 3

// Space management
#define DYNAMIC_KEYMAP_LAYER_COUNT 16

// RGB Effects and Settings

#ifdef RGBLIGHT_ENABLE
#define RGBLIGHT_EFFECT_BREATHING
#define RGBLIGHT_EFFECT_RAINBOW_MOOD
#define RGBLIGHT_EFFECT_RAINBOW_SWIRL
#define RGBLIGHT_EFFECT_SNAKE
#define RGBLIGHT_EFFECT_KNIGHT
#define RGBLIGHT_EFFECT_CHRISTMAS
#define RGBLIGHT_EFFECT_STATIC_GRADIENT
#define RGBLIGHT_LIMIT_VAL 120
#define RGBLIGHT_HUE_STEP 10
#define RGBLIGHT_SAT_STEP 17
#define RGBLIGHT_VAL_STEP 17
#endif

#ifdef RGB_MATRIX_ENABLE
#define RGB_MATRIX_KEYPRESSES
#define RGB_DISABLE_WHEN_USB_SUSPENDED
#define RGB_MATRIX_FRAMEBUFFER_EFFECTS
#define RGB_MATRIX_MAXIMUM_BRIGHTNESS 255
#define RGB_MATRIX_HUE_STEP 4
#define RGB_MATRIX_SAT_STEP 8
#define RGB_MATRIX_VAL_STEP 8
#define RGB_MATRIX_SPD_STEP 10
#define ENABLE_RGB_MATRIX_ALPHAS_MODS                // Static dual hue, speed is hue for secondary hue
#define ENABLE_RGB_MATRIX_GRADIENT_UP_DOWN           // Static gradient top to bottom, speed controls how much gradient changes
#define ENABLE_RGB_MATRIX_GRADIENT_LEFT_RIGHT        // Static gradient left to right, speed controls how much gradient changes
#define ENABLE_RGB_MATRIX_BREATHING                  // Single hue brightness cycling animation
#define ENABLE_RGB_MATRIX_BAND_SAT                   // Single hue band fading saturation scrolling left to right
#define ENABLE_RGB_MATRIX_BAND_VAL                   // Single hue band fading brightness scrolling left to right
#define ENABLE_RGB_MATRIX_BAND_PINWHEEL_SAT          // Single hue 3 blade spinning pinwheel fades saturation
#define ENABLE_RGB_MATRIX_BAND_PINWHEEL_VAL          // Single hue 3 blade spinning pinwheel fades brightness
#define ENABLE_RGB_MATRIX_BAND_SPIRAL_SAT            // Single hue spinning spiral fades saturation
#define ENABLE_RGB_MATRIX_BAND_SPIRAL_VAL            // Single hue spinning spiral fades brightness
#define ENABLE_RGB_MATRIX_CYCLE_ALL                  // Full keyboard solid hue cycling through full gradient
#define ENABLE_RGB_MATRIX_CYCLE_LEFT_RIGHT           // Full gradient scrolling left to right
#define ENABLE_RGB_MATRIX_CYCLE_UP_DOWN              // Full gradient scrolling top to bottom
#define ENABLE_RGB_MATRIX_CYCLE_OUT_IN               // Full gradient scrolling out to in
#define ENABLE_RGB_MATRIX_CYCLE_OUT_IN_DUAL          // Full dual gradients scrolling out to in
#define ENABLE_RGB_MATRIX_RAINBOW_MOVING_CHEVRON     // Full gradient Chevron shapped scrolling left to right
#define ENABLE_RGB_MATRIX_CYCLE_PINWHEEL             // Full gradient spinning pinwheel around center of keyboard
#define ENABLE_RGB_MATRIX_CYCLE_SPIRAL               // Full gradient spinning spiral around center of keyboard
#define ENABLE_RGB_MATRIX_DUAL_BEACON                // Full gradient spinning around center of keyboard
#define ENABLE_RGB_MATRIX_RAINBOW_BEACON             // Full tighter gradient spinning around center of keyboard
#define ENABLE_RGB_MATRIX_RAINBOW_PINWHEELS          // Full dual gradients spinning two halfs of keyboard
#define ENABLE_RGB_MATRIX_FLOWER_BLOOMING            // Full tighter gradient of first half scrolling left to right and second half scrolling right to left
#define ENABLE_RGB_MATRIX_RAINDROPS                  // Randomly changes a single key's hue
#define ENABLE_RGB_MATRIX_JELLYBEAN_RAINDROPS        // Randomly changes a single key's hue and saturation
#define ENABLE_RGB_MATRIX_HUE_BREATHING              // Hue shifts up a slight ammount at the same time, then shifts back
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

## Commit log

2025-03-01 Fix #6, layer shift timing issue
    [config.h]
2025-03-08 Add pipeline
    Skip release if tag already exists
    Make sure to fetch tags
    Add Quickstart link to README.md
    [config.h]
2025-04-15 Configure led count
2025-04-21 v0.1.0 release, full RGB support, case STLs
    Fully-tested firmware with RGB support
    Added STL's for the case
    Updated the roadmap
    This concludes v0.1.0 release
    [bottom-left.stl, bottom-right.stl, top-left.stl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]
2025-04-21 Typo in stl readme
2025-04-24 Audo mount rp2040
    Script to mount rp2040
2025-10-04 Use generic rp2040 MCU rather than atmega32u4
    atmega32u4 will not be supported from here on out
    Fix json parse error
    [config.h]
2025-11-20 v1.0.0 initial release, with pcb files
    [alpha_centauri_pcb.kicad_sch, keyboard_l.kicad_sch, keyboard_r.kicad_sch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]
2026-07-26 Initial PCB v1.1.0 updates, including 4-layer restructure
    [alpha_centauri_pcb.kicad_pcb, alpha_centauri_pcb.kicad_sch, keyboard_l.kicad_sch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]
2026-07-26 Add .kicad_pro to git
2026-07-27 Include components as a path in the repository
    [alpha_centauri_pcb.kicad_pcb, keyboard_l.kicad_sch, keyboard_r.kicad_sch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]
